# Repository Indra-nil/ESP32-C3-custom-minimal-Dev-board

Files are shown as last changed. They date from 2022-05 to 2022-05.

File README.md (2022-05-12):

# ESP32-C3 custom minimal Dev board
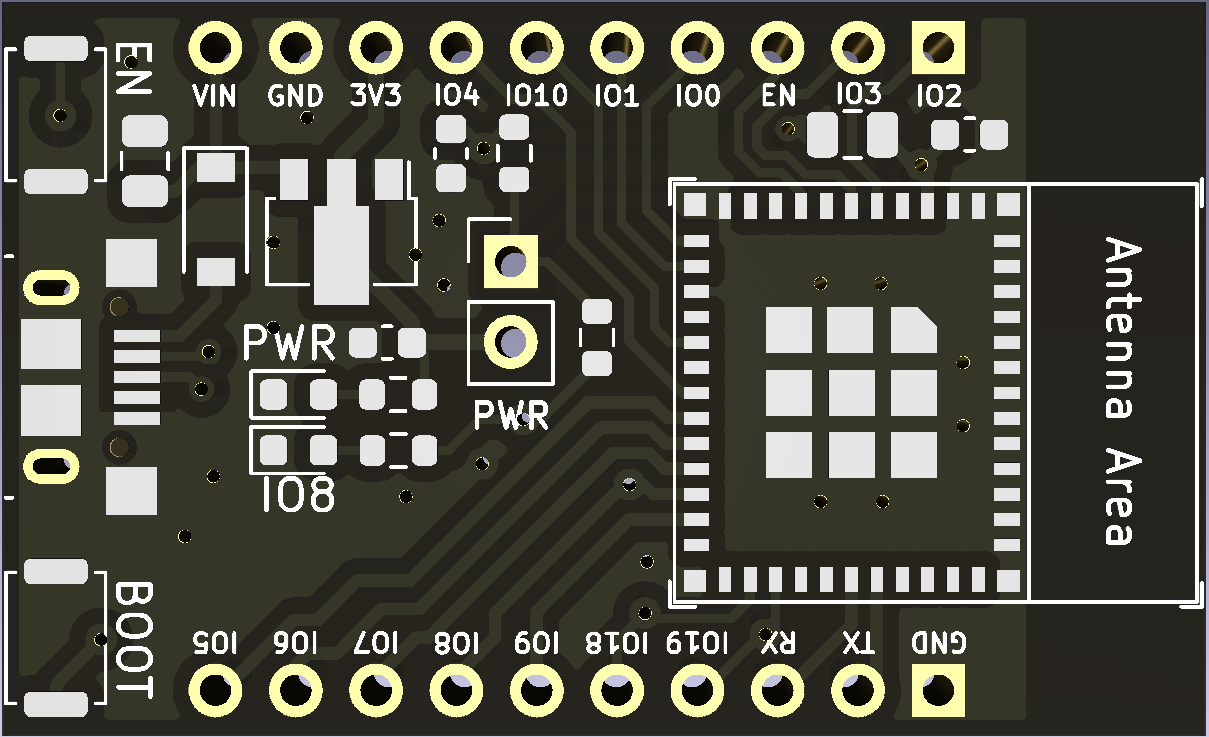
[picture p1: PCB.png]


This board based on ESP32-C3-MINI-1. To reduce power consumption for battery operations and PCB dimension, dedicated USB to UART converter not used. The USB directly connected to Serial/JTAG controller of ESP32-C3 (GPIO18 and GPIO19). This can be used as CDC-ACM virtual serial port, programming embedded/external flash, CPU debugging with compact JTAG instructions.

### The power jumper should shorted with a shunt for normal operations. This pins are helpful for measuring current consumption (fast switching currents) using power analyzers(PPK2, Otii Arc etc).

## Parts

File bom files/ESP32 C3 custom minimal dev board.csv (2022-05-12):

Ref | Qnty | Value | Cmp name | Footprint | MPN
C1, C5, | 2 | 1u | C | Capacitor_SMD:C_0603_1608Metric | CC0603KRX5R6BB105
C2, C4, | 2 | 10u | C | Capacitor_SMD:C_0805_2012Metric | CC0805KRX5R6BB106
C3, | 1 | 100n | C | Capacitor_SMD:C_0603_1608Metric | CC0603KRX7R9BB104
D1, | 1 | PWR | LED | LED_SMD:LED_0603_1608Metric | 19-217/R6C-AL1M2VY/3T
D2, | 1 | IO8 | LED | LED_SMD:LED_0603_1608Metric | 19-217/B7C-ZL2N1B3X/3T
D3, | 1 | 1N5819 | 1N5819 | Diode_SMD:D_SOD-123 | 1N5819HW-7-F
J1, | 1 | USB_B_Micro | USB_B_Micro | MUP-U513:MUP-U513 | MUP-U513
J2, | 1 | PWR | Conn_01x02_Male | Connector_PinHeader_2.54mm:PinHeader_1x02_P2.54mm_Vertical
J3, J4, | 2 | Conn | Conn_01x10_Male | Connector_PinHeader_2.54mm:PinHeader_1x10_P2.54mm_Vertical
R1, R2, | 2 | 10k | R | Resistor_SMD:R_0603_1608Metric | RC0603FR-0710KL
R3, R4, | 2 | 1k | R | Resistor_SMD:R_0603_1608Metric | RC0603FR-071KL
SW1, | 1 | EN | SW_Push | Button_Switch_SMD:SW_Push_SPST_NO_Alps_SKRK | SKRKAEE020
SW2, | 1 | BOOT | SW_Push | Button_Switch_SMD:SW_Push_SPST_NO_Alps_SKRK | SKRKAEE020
U1, | 1 | ESP32-C3-MINI-1 | ESP32-C3-MINI-1 | Espressif:ESP32-C3-MINI-1 | ESP32-C3-MINI-1-N4
U2, | 1 | AZ1117-3.3 | AZ1117-3.3 | Package_TO_SOT_SMD:SOT-89-3 | AZ1117CR-3.3TRG1
J5 | 1 |  | CONN SHUNT 2POS |  | SNT-100-RD-G

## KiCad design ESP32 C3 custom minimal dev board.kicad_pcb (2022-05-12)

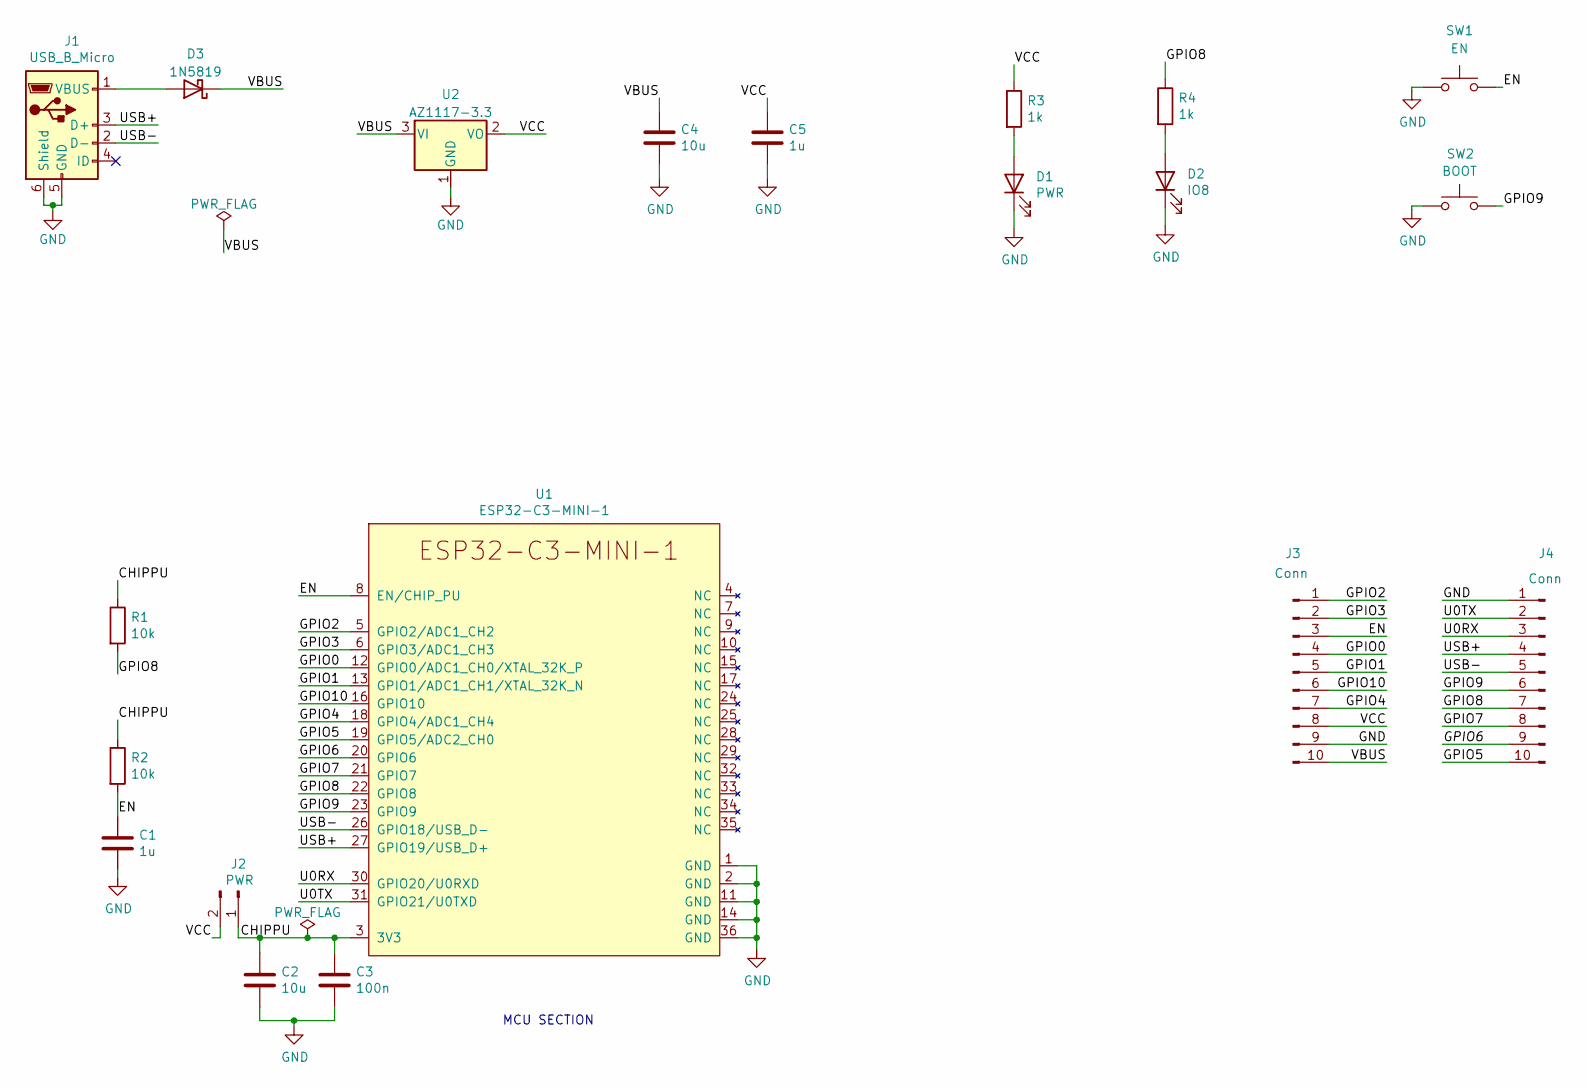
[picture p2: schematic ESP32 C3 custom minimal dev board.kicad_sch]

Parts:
C1, C5: 1u; C_0603_1608Metric
C2, C4: 10u; C_0805_2012Metric
C3: 100n; C_0603_1608Metric
D1: PWR; LED_0603_1608Metric
D2: IO8; LED_0603_1608Metric
D3: 1N5819; D_SOD-123
J1: USB_B_Micro; MUP-U513
J2: PWR; PinHeader_1x02_P2.54mm_Vertical
J3, J4: Conn; PinHeader_1x10_P2.54mm_Vertical
R1, R2: 10k; R_0603_1608Metric
R3, R4: 1k; R_0603_1608Metric
SW1: EN; SW_Push_SPST_NO_Alps_SKRK
SW2: BOOT; SW_Push_SPST_NO_Alps_SKRK
U1: ESP32-C3-MINI-1
U2: AZ1117-3.3; SOT-89-3

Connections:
/CHIPPU: C2.1, C3.1, J2.1, R1.1, R2.1, U1.3 (3V3)
/EN: C1.1, J3.3, R2.2, SW1.2, U1.8 (EN/CHIP_PU)
/GPIO0: J3.4, U1.12 (GPIO0/ADC1_CH0/XTAL_32K_P)
/GPIO1: J3.5, U1.13 (GPIO1/ADC1_CH1/XTAL_32K_N)
/GPIO2: J3.1, U1.5 (GPIO2/ADC1_CH2)
/GPIO3: J3.2, U1.6 (GPIO3/ADC1_CH3)
/GPIO4: J3.7, U1.18 (GPIO4/ADC1_CH4)
/GPIO5: J4.10, U1.19 (GPIO5/ADC2_CH0)
/GPIO6: J4.9, U1.20 (GPIO6)
/GPIO7: J4.8, U1.21 (GPIO7)
/GPIO8: J4.7, R1.2, R4.1, U1.22 (GPIO8)
/GPIO9: J4.6, SW2.2, U1.23 (GPIO9)
/GPIO10: J3.6, U1.16 (GPIO10)
/U0RX: J4.3, U1.30 (GPIO20/U0RXD)
/U0TX: J4.2, U1.31 (GPIO21/U0TXD)
/USB+: J1.3 (D+), J4.4, U1.27 (GPIO19/USB_D+)
/USB-: J1.2 (D-), J4.5, U1.26 (GPIO18/USB_D-)
/VBUS: C4.1, D3.1 (K), J3.10, U2.3 (VI)
/VCC: C5.1, J2.2, J3.8, R3.1, U2.2 (VO)
GND: C1.2, C2.2, C3.2, C4.2, C5.2, D1.1 (K), D2.1 (K), J1.5 (GND), J1.6 (Shield), J3.9, J4.1, SW1.1, SW2.1, U1.1 (GND), U1.2 (GND), U1.11 (GND), U1.14 (GND), U1.36 (GND), U2.1 (GND)
unnamed: D1.2 (A), R3.2
unnamed: D2.2 (A), R4.2
unnamed: D3.2 (A), J1.1 (VBUS)

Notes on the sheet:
MCU SECTION

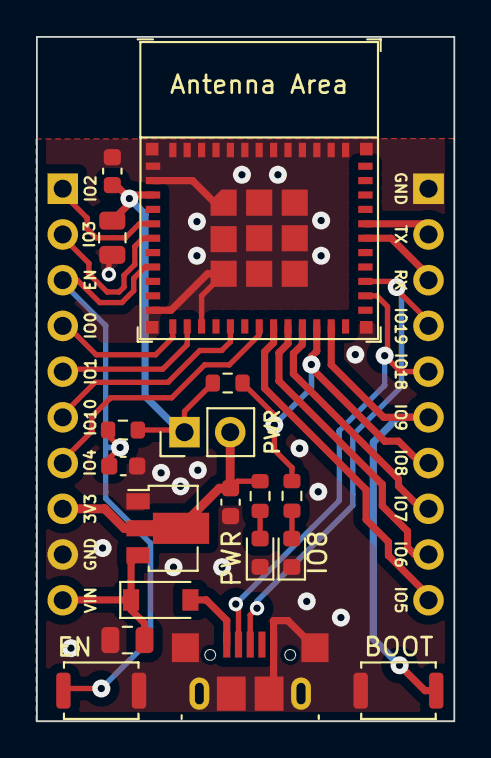
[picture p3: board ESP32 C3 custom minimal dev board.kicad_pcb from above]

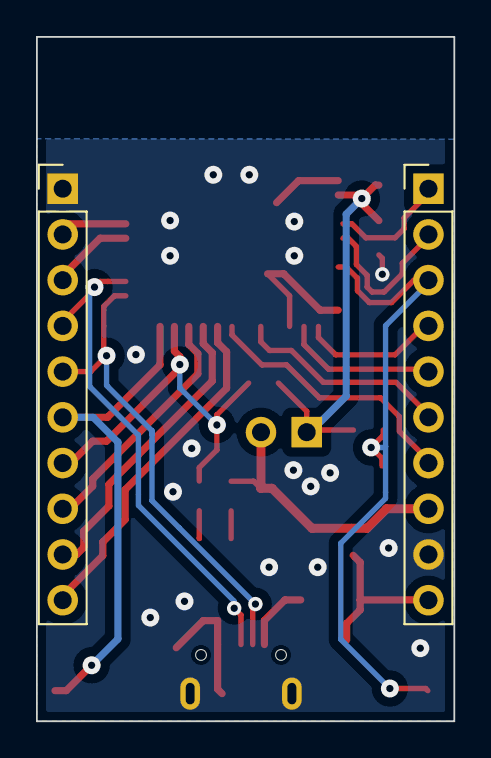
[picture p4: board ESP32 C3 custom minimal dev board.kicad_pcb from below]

Board: 2 copper layers, 23.2 x 38.0 mm, 20 parts (2 on the bottom side), 23 nets.
